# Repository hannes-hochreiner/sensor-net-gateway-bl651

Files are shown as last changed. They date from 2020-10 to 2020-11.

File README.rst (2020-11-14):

SensorNet Gateway BL651
=======================

A gateway for the SensorNet project, based on the BL651 module.

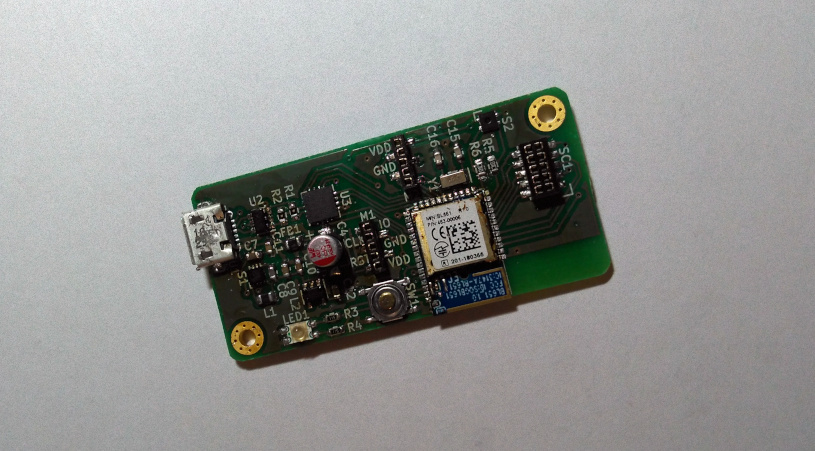
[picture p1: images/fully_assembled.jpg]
fully assembled board


Functional Test
---------------

+------------------+--------+
| feature          | status |
+==================+========+
| Power Management | OK     |
+------------------+--------+
| SWD              | OK     |
+------------------+--------+
| USB              | OK     |
+------------------+--------+
| LED              | OK     |
+------------------+--------+
| Sensor           | OK     |
+------------------+--------+

Firmware
--------

Firmware for this board can be found in the repository `"hannes-hochreiner/sensor-net-nrf52810-firmware" <https://github.com/hannes-hochreiner/sensor-net-nrf52810-firmware>`_

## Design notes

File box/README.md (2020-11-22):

Box Parameters
==============

PCB size
--------

24 x 50 x 1.6 mm

Mounting holes are M2; centers are 3 x 3 mm from corner

Components
----------

  * top side head room: 5.5 mm
  * Stand-off for inserts: 6 x 6 x 4 mm (5 mm in z recommended); hole diameter 3.2 mm; insert hight 4 mm
  * USB connector: cut-out 8.6 (8.2) x 3.4 (3) mm; center is 7 mm from PCB edge and 1.25 mm above PCB (1.25 + 1.6 + 4 = 6.85 mm from bottom of box)
  * Sensor: center on board 154,92; top left of board 152,82 => -10,15 from center of board

Required inner measurements
---------------------------

  * Height: 6 (5.5) + 4 + 2 (1.6) = 12 mm
  * Width: 24 + 2 x 6 = 36 mm
  * Depth: 50.2 (50) mm

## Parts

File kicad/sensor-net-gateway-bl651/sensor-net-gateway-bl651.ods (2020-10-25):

Status | Reference | Value | Footprint | Description | Digi-Key Part Number | Manufacturer | Manufacturer Part Number | DigiKey_PartNumber | Manufacturer_PartNumber
n/a | H2 | MountingHole | MountingHole:MountingHole_2.2mm_M2_Pad_Via
n/a | H1 | MountingHole | MountingHole:MountingHole_2.2mm_M2_Pad_Via
n/a | L3 | logo | HH_Hochreiner:logo
have | BL1 | BL651 | HH_Laird:BL651 | RX TXRX MODULE BT TRC ANT SMD | 453-00005CT-ND | Laird Connectivity Inc. | 453-00005
have | C14 | 0.1µF,16V | Capacitor_SMD:C_0603_1608Metric
order | Y1 | 32.768 kHz | Crystal:Crystal_SMD_MicroCrystal_CC7V-T1A-2Pin_3.2x1.5mm | CRYSTAL 32.7680KHZ 9PF SMD | 2195-CM7V-T1A-32.768KHZ-9PF-10PPM-TA-QCCT-ND | Micro Crystal AG | CM7V-T1A-32.768KHZ-9PF-10PPM-TA-QC
order | C15 | 9pF | Capacitor_SMD:C_0603_1608Metric |  | 311-3866-1-ND | Yageo | CC0603CRNPO9BN9R0
order | C16 | 9pF | Capacitor_SMD:C_0603_1608Metric |  | 311-3866-1-ND | Yageo | CC0603CRNPO9BN9R0
order | SW1 | PTS526_SM15_SMTR2_LFS | HH_CnK:PTS526-SM15-SMTR2-LFS | TACT 5.2 X 5.2, 1.5 MM H, 160GF | CKN12220-1-ND | C&K | PTS526 SM15 SMTR2 LFS
have | C13 | 0.1µF,16V | Capacitor_SMD:C_0603_1608Metric
order | SC1 | Sensor-Connector | HH_Hochreiner:Sensor-Connector_M50-3150542R | CONN RCPT 10POS 0.05 GOLD SMD | 952-3493-1-ND | Harwin Inc. | M50-3150542R
order | M1 | M50-3130545 | HH_Harwin:M50-3130545 |  | 952-3585-ND | Harwin Inc. |  | 952-3585-ND | M50-3130545
order | M2 | M50-3130545 | HH_Harwin:M50-3130545 |  | 952-3585-ND | Harwin Inc. |  | 952-3585-ND | M50-3130545
order | LED1 | APBD3224LSURKCGKC | HH_Kingbright:APBD3224LSURKCGKC | LED GREEN/RED CLEAR 4SMD | 754-1962-1-ND | Kingbright | APBD3224LSURKCGKC
order | R3 | 510 | Resistor_SMD:R_0603_1608Metric |  | RR08P510DCT-ND | Susumu | RR0816P-511-D
order | R4 | 510 | Resistor_SMD:R_0603_1608Metric |  | RR08P510DCT-ND | Susumu | RR0816P-511-D
have | C7 | 4.7µF | Capacitor_SMD:C_0603_1608Metric |  | 1276-1907-1-ND | Samsung Electro-Mechanics |  | 1276-1907-1-ND | CL10A475MQ8NNNC
have | L1 | 1µH | Inductor_SMD:L_0805_2012Metric |  |  |  |  | 445-6391-1-ND
order | C9 | 4.7µF | Capacitor_SMD:C_0603_1608Metric |  | 1276-1907-1-ND |  |  | 1276-1907-1-ND
have | C8 | 560pF | Capacitor_SMD:C_0603_1608Metric |  |  |  |  | 1276-2315-1-ND
have | C10 | 0.47µF | Capacitor_SMD:C_0603_1608Metric |  |  |  |  | 1276-2082-1-ND
have | C12 | 10µF | Capacitor_SMD:C_0603_1608Metric |  |  |  |  | 1276-1119-1-ND
have | S1 | MIC23050-SYML-TR | HH_MicrochipTechnology:MIC23050-SYML-TR | IC REG BUCK 3.3V 600MA 8MLF | 576-3351-1-ND | Microchip Technology | MIC23050-SYML-TR
have | L2 | MIC94310-MYM5-TR | Package_TO_SOT_SMD:SOT-23-5 | IC REG LINEAR 2.8V 200MA SOT23-5 | MIC94310-MYM5-CT-ND | Microchip Technology | MIC94310-MYM5-TR
have | C1 | 0.1µF | Capacitor_SMD:C_0603_1608Metric
have | C2 | 47pF | Capacitor_SMD:C_0603_1608Metric
have | C3 | 47pF | Capacitor_SMD:C_0603_1608Metric
have | R2 | 27R | Resistor_SMD:R_0603_1608Metric
have | R1 | 27R | Resistor_SMD:R_0603_1608Metric
have | C11 | 10nF | Capacitor_SMD:C_0603_1608Metric
have | C6 | 0.1µF | Capacitor_SMD:C_0603_1608Metric
have | C4 | 4.7µF | HH_WurthElektronik:865080640004 |  |  | Wurth Electronics Inc. |  | 732-8449-1-ND | 865080640004
have | C5 | 0.1µF | Capacitor_SMD:C_0603_1608Metric
have | C21 | 0.1µF | Capacitor_SMD:C_0603_1608Metric
have | U3 | FT230XQ | Package_DFN_QFN:QFN-16-1EP_4x4mm_P0.65mm_EP2.1x2.1mm | IC USB SERIAL BASIC UART 16QFN | 768-1130-1-ND | FTDI, Future Technology Devices International Ltd | FT230XQ-R
have | U1 | USB_micro_ab | HH_Molex:MOLEX_USB_MICRO_0475890001 | CONN RCPT MICRO USB AB 5P SMD RA | WM17143CT-ND | Molex | 0475890001
have | U2 | USBLC6-2SC6 | HH_STMicroelectronics:USBLC6-2SC6_SOT-23-6 | TVS DIODE 5.25V 17V SOT23-6 | 497-5235-1-ND | STMicroelectronics | USBLC6-2SC6
have | FB1 | Ferrite_Bead | Capacitor_SMD:C_0805_2012Metric | FERRITE BEAD 600 OHM 0805 1LN | 240-2390-1-ND | Laird-Signal Integrity Products | MI0805K601R-10
have | S2 | SHTC3 | HH_Sensirion:SHTC3 |  | 1649-1105-1-ND | Sensirion AG | SHTC3
have | R6 | 10k | Resistor_SMD:R_0603_1608Metric
have | R5 | 10k | Resistor_SMD:R_0603_1608Metric
have | C17 | 0.1µF | Capacitor_SMD:C_0603_1608Metric

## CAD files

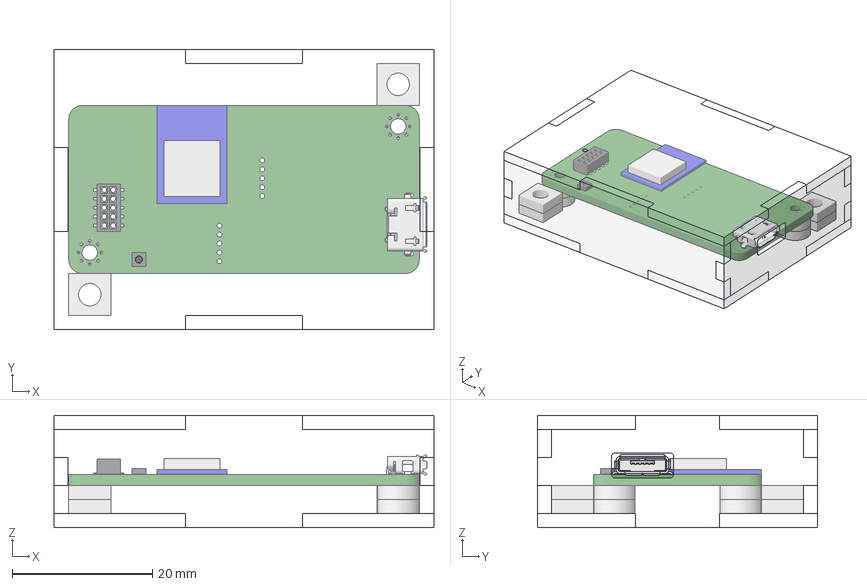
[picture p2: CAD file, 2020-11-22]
box/model.FCStd
54.2 x 40.0 x 16.0 mm
front
left
right
bottom
case_mounting_1_1
case_mounting_1_2
case_mounting_2_2
case_mounting_2_1
pcb_mount_1_1
pcb_mount_1_2
pcb_mount_2_1
pcb_mount_2_2
top
back

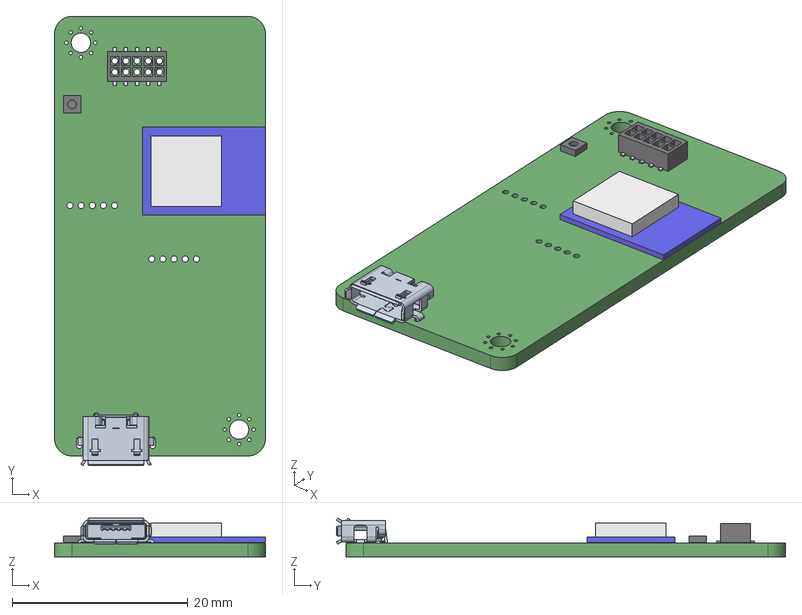
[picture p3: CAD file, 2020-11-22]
kicad/sensor-net-gateway-bl651/sensor-net-gateway-bl651.step
24.0 x 51.1 x 4.41 mm

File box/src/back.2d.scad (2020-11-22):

use <../lib/side.scad>

module back() {
  difference() {
    side_front_back(36,12,2);
    translate([-5,-12/2+6.85,0]) {
      offset(r=.3,$nf=50)
      polygon(points=[[-4.1,-1.5],[4.1,-1.5],[4.1,1.5],[-4.1,1.5],],convexity=10);
    }
  }
}

back();

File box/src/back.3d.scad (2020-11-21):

use <back.2d.scad>;

rotate([90,0,90]) {
  linear_extrude(height = 2, center = true, convexity = 10, twist = 0) {
    back();
  }
}

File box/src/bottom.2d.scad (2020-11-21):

use <../lib/side.scad>;

module bottom() {
  difference() {
    side_top_bottom(50.2,36,2);
    translate([-22,-15,0]) {
      circle(d=2.2, $fn=50);
    }
    translate([22,15,0]) {
      circle(d=2.2, $fn=50);
    }
  }
}

bottom();

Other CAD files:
box/src/bottom.3d.scad
box/src/box_mount.2d.scad
box/src/box_mount.3d.scad
box/src/combined.scad
box/src/front.2d.scad
box/src/front.3d.scad
box/src/left.2d.scad
box/src/left.3d.scad
box/src/mounting.2d.scad
box/src/mounting.3d.scad
box/src/pcb_mount.2d.scad
box/src/pcb_mount.3d.scad
box/src/top.2d.scad
box/src/top.3d.scad

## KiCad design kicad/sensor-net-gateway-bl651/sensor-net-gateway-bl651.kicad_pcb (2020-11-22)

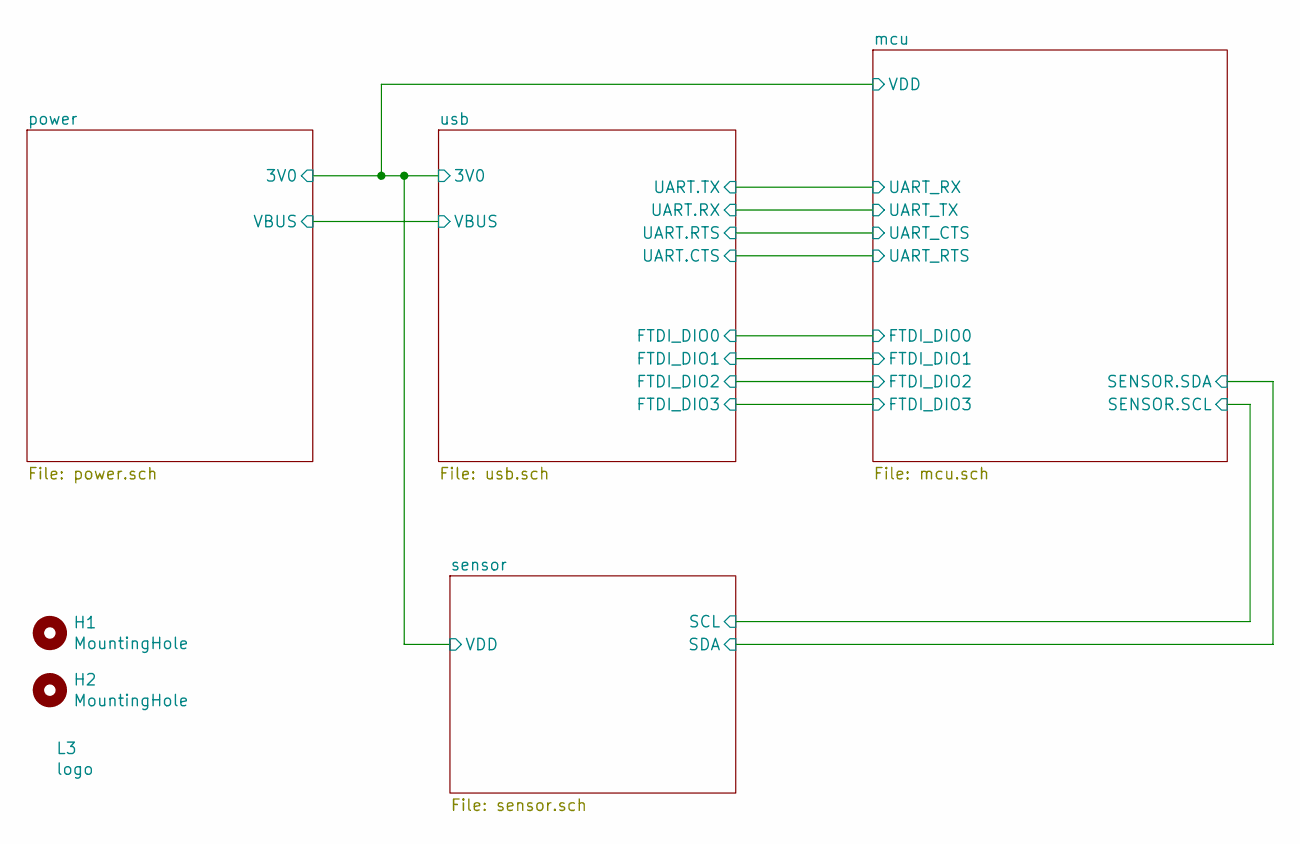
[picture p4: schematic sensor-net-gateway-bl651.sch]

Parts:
H1, H2: MountingHole; MountingHole_2.2mm_M2_Pad_Via
L3: logo

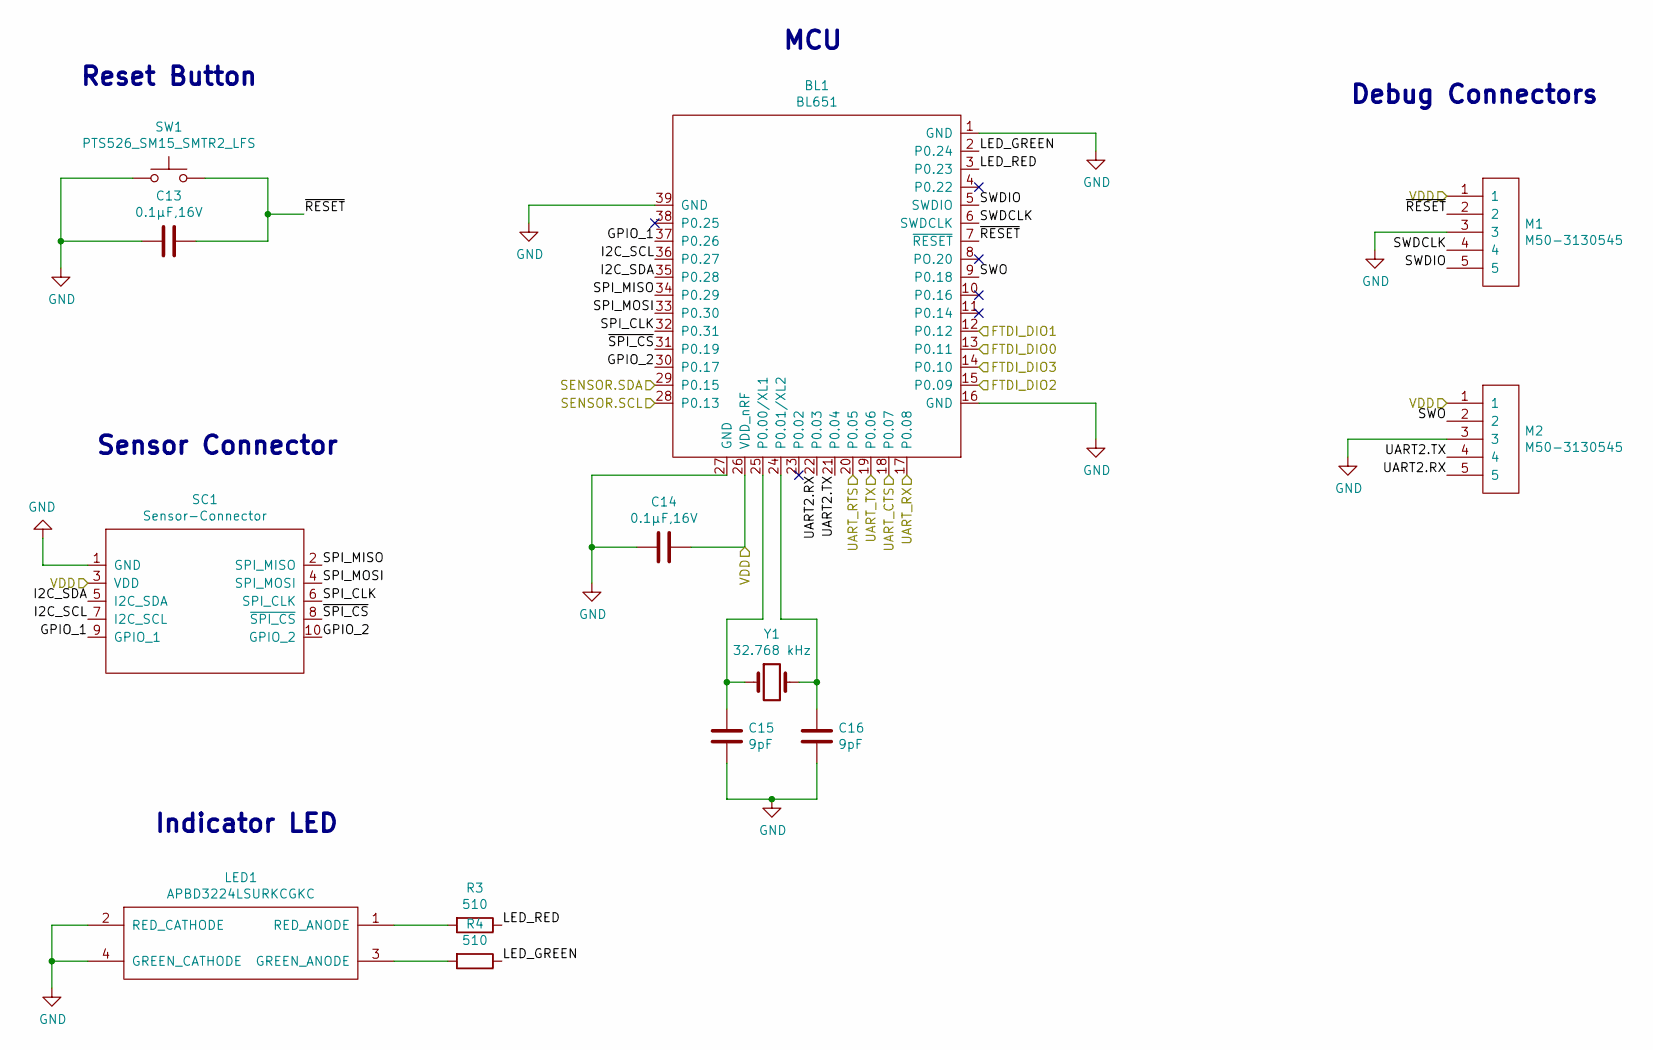
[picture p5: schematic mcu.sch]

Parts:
BL1: BL651; Manufacturer Part Number 453-00005; Digi-Key Part Number 453-00005CT-ND
C13, C14: 0.1µF,16V; C_0603_1608Metric
C15, C16: 9pF; C_0603_1608Metric; Manufacturer Part Number CC0603CRNPO9BN9R0; Digi-Key Part Number 311-3866-1-ND
LED1: APBD3224LSURKCGKC; Manufacturer Part Number APBD3224LSURKCGKC; Digi-Key Part Number 754-1962-1-ND
M1, M2: M50-3130545; Manufacturer_PartNumber M50-3130545; DigiKey_PartNumber 952-3585-ND
R3, R4: 510; R_0603_1608Metric; Manufacturer Part Number RR0816P-511-D; Digi-Key Part Number RR08P510DCT-ND
SC1: Sensor-Connector; Sensor-Connector_M50-3150542R; Manufacturer Part Number M50-3150542R; Digi-Key Part Number 952-3493-1-ND
SW1: PTS526_SM15_SMTR2_LFS; PTS526-SM15-SMTR2-LFS; Manufacturer Part Number PTS526 SM15 SMTR2 LFS; Digi-Key Part Number CKN12220-1-ND
Y1: 32.768 kHz; Crystal_SMD_MicroCrystal_CC7V-T1A-2Pin_3.2x1.5mm; Manufacturer Part Number CM7V-T1A-32.768KHZ-9PF-10PPM-TA-QC; Digi-Key Part Number 2195-CM7V-T1A-32.768KHZ-9PF-10PPM-TA-QC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

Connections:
/mcu/FTDI_DIO0: BL1.13 (P0.11); also elsewhere on the board
/mcu/FTDI_DIO1: BL1.12 (P0.12); also elsewhere on the board
/mcu/FTDI_DIO2: BL1.15 (P0.09); also elsewhere on the board
/mcu/FTDI_DIO3: BL1.14 (P0.10); also elsewhere on the board
/mcu/GPIO_1: BL1.37 (P0.26), SC1.9 (GPIO_1)
/mcu/GPIO_2: BL1.30 (P0.17), SC1.10 (GPIO_2)
/mcu/I2C_SCL: BL1.36 (P0.27), SC1.7 (I2C_SCL)
/mcu/I2C_SDA: BL1.35 (P0.28), SC1.5 (I2C_SDA)
/mcu/LED_GREEN: BL1.2 (P0.24), R4.1
/mcu/LED_RED: BL1.3 (P0.23), R3.1
/mcu/SPI_CLK: BL1.32 (P0.31), SC1.6 (SPI_CLK)
/mcu/SPI_MISO: BL1.34 (P0.29), SC1.2 (SPI_MISO)
/mcu/SPI_MOSI: BL1.33 (P0.30), SC1.4 (SPI_MOSI)
/mcu/SWDCLK: BL1.6 (SWDCLK), M1.4
/mcu/SWDIO: BL1.5 (SWDIO), M1.5
/mcu/SWO: BL1.9 (P0.18), M2.2
/mcu/UART2.RX: BL1.22 (P0.03), M2.5
/mcu/UART2.TX: BL1.21 (P0.04), M2.4
/mcu/~RESET: BL1.7 (~RESET), C13.1, M1.2, SW1.2
/mcu/~SPI_CS: BL1.31 (P0.19), SC1.8 (~SPI_CS)
/power/3V0: BL1.26 (VDD_nRF), C14.1, M1.1, M2.1, SC1.3 (VDD); also elsewhere on the board
/sensor/SCL: BL1.28 (P0.13); also elsewhere on the board
/sensor/SDA: BL1.29 (P0.15); also elsewhere on the board
/usb/UART.CTS: BL1.20 (P0.05); also elsewhere on the board
/usb/UART.RTS: BL1.18 (P0.07); also elsewhere on the board
/usb/UART.RX: BL1.19 (P0.06); also elsewhere on the board
/usb/UART.TX: BL1.17 (P0.08); also elsewhere on the board
GND: BL1.1 (GND), BL1.16 (GND), BL1.27 (GND), BL1.39 (GND), C13.2, C14.2, C15.2, C16.2, LED1.2 (RED_CATHODE), LED1.4 (GREEN_CATHODE), M1.3, M2.3, SC1.1 (GND), SW1.1; also elsewhere on the board
unnamed: BL1.24 (P0.01/XL2), C16.1, Y1.2
unnamed: BL1.25 (P0.00/XL1), C15.1, Y1.1
unnamed: LED1.1 (RED_ANODE), R3.2
unnamed: LED1.3 (GREEN_ANODE), R4.2

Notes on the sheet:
Indicator LED
Sensor Connector
Reset Button
MCU
Debug Connectors

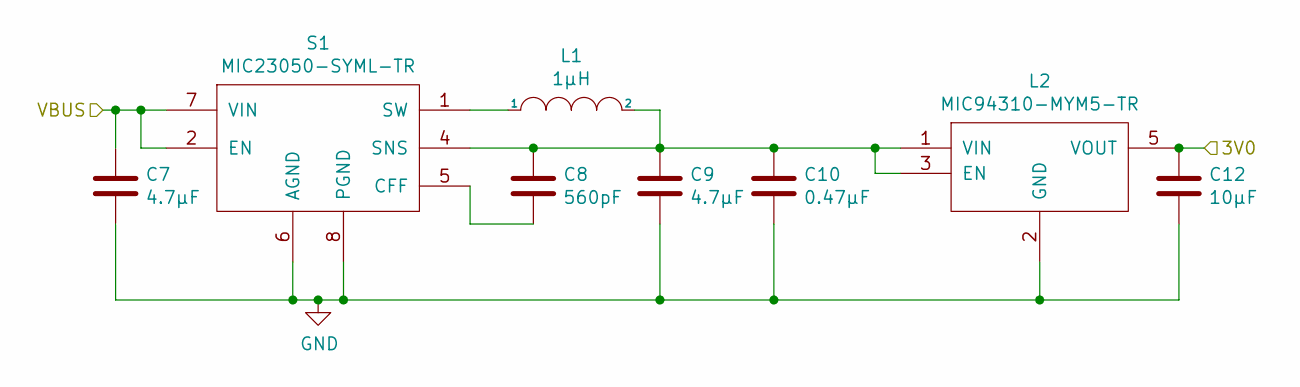
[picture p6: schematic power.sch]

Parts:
C7: 4.7µF; C_0603_1608Metric; Manufacturer_PartNumber CL10A475MQ8NNNC; DigiKey_PartNumber 1276-1907-1-ND
C8: 560pF; C_0603_1608Metric; DigiKey_PartNumber 1276-2315-1-ND
C9: 4.7µF; C_0603_1608Metric; DigiKey_PartNumber 1276-1907-1-ND
C10: 0.47µF; C_0603_1608Metric; DigiKey_PartNumber 1276-2082-1-ND
C12: 10µF; C_0603_1608Metric; DigiKey_PartNumber 1276-1119-1-ND
L1: 1µH; L_0805_2012Metric; DigiKey_PartNumber 445-6391-1-ND
L2: MIC94310-MYM5-TR; SOT-23-5; Manufacturer Part Number MIC94310-MYM5-TR; Digi-Key Part Number MIC94310-MYM5-CT-ND
S1: MIC23050-SYML-TR; Manufacturer Part Number MIC23050-SYML-TR; Digi-Key Part Number 576-3351-1-ND

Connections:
/power/3V0: C12.1, L2.5 (VOUT); also elsewhere on the board
/power/VBUS: C7.1, S1.2 (EN), S1.7 (VIN); also elsewhere on the board
GND: C7.2, C9.2, C10.2, C12.2, L2.2 (GND), S1.6 (AGND), S1.8 (PGND); also elsewhere on the board
unnamed: C8.2, S1.5 (CFF)
unnamed: C8.1, C9.1, C10.1, L1.2, L2.1 (VIN), L2.3 (EN), S1.4 (SNS)
unnamed: L1.1, S1.1 (SW)

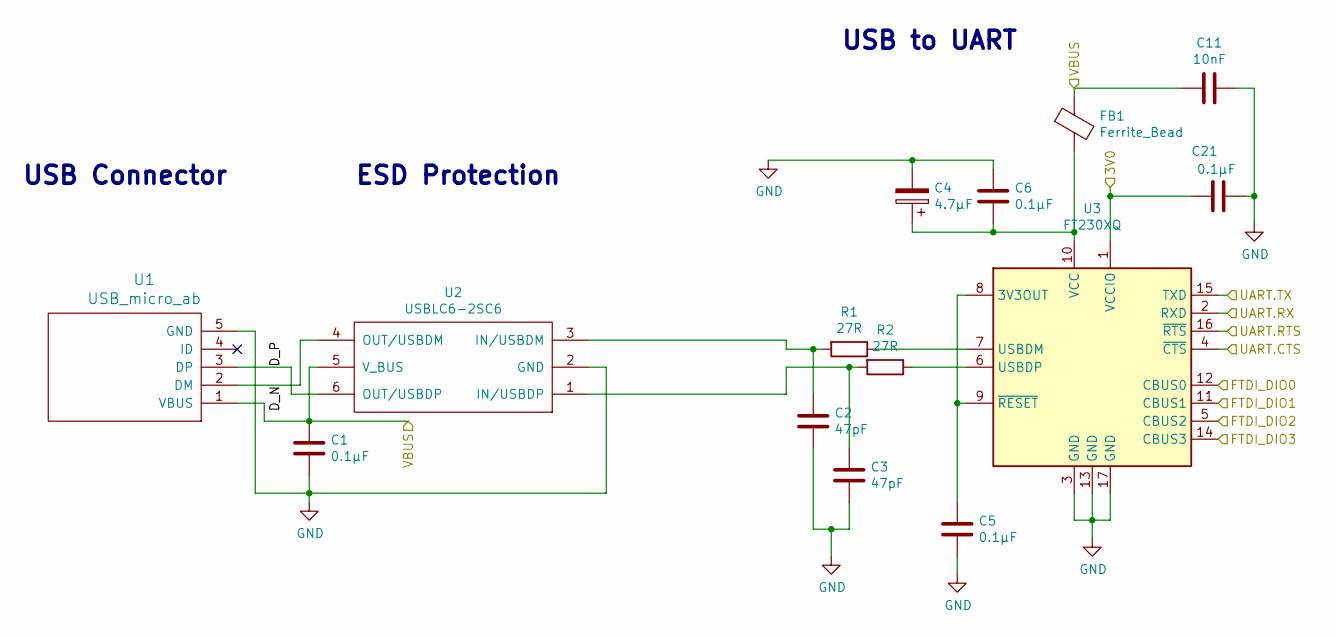
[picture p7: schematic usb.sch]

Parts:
C1, C5, C6, C21: 0.1µF; C_0603_1608Metric
C2, C3: 47pF; C_0603_1608Metric
C4: 4.7µF; 865080640004; Manufacturer_PartNumber 865080640004; DigiKey_PartNumber 732-8449-1-ND
C11: 10nF; C_0603_1608Metric
FB1: Ferrite_Bead; C_0805_2012Metric; Manufacturer Part Number MI0805K601R-10; Digi-Key Part Number 240-2390-1-ND
R1, R2: 27R; R_0603_1608Metric
U1: USB_micro_ab; MOLEX_USB_MICRO_0475890001; Manufacturer Part Number 0475890001; Digi-Key Part Number WM17143CT-ND
U2: USBLC6-2SC6; USBLC6-2SC6_SOT-23-6; Manufacturer Part Number USBLC6-2SC6; Digi-Key Part Number 497-5235-1-ND
U3: FT230XQ; QFN-16-1EP_4x4mm_P0.65mm_EP2.1x2.1mm; Manufacturer Part Number FT230XQ-R; Digi-Key Part Number 768-1130-1-ND

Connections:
/mcu/FTDI_DIO0: U3.12 (CBUS0); also elsewhere on the board
/mcu/FTDI_DIO1: U3.11 (CBUS1); also elsewhere on the board
/mcu/FTDI_DIO2: U3.5 (CBUS2); also elsewhere on the board
/mcu/FTDI_DIO3: U3.14 (CBUS3); also elsewhere on the board
/power/3V0: C21.1, U3.1 (VCCIO); also elsewhere on the board
/power/VBUS: C1.1, C11.1, FB1.1, U1.1 (VBUS), U2.5 (V_BUS); also elsewhere on the board
/usb/D_N: U1.2 (DM), U2.4 (OUT/USBDM)
/usb/D_P: U1.3 (DP), U2.6 (OUT/USBDP)
/usb/UART.CTS: U3.4 (~CTS); also elsewhere on the board
/usb/UART.RTS: U3.16 (~RTS); also elsewhere on the board
/usb/UART.RX: U3.2 (RXD); also elsewhere on the board
/usb/UART.TX: U3.15 (TXD); also elsewhere on the board
GND: C1.2, C2.2, C3.2, C4.2, C5.2, C6.1, C11.2, C21.2, U1.5 (GND), U2.2 (GND), U3.3 (GND), U3.13 (GND), U3.17 (GND); also elsewhere on the board
unnamed: C2.1, R1.2, U2.3 (IN/USBDM)
unnamed: C3.1, R2.2, U2.1 (IN/USBDP)
unnamed: C4.1, C6.2, FB1.2, U3.10 (VCC)
unnamed: C5.1, U3.8 (3V3OUT), U3.9 (~RESET)
unnamed: R1.1, U3.7 (USBDM)
unnamed: R2.1, U3.6 (USBDP)

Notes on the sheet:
USB Connector
ESD Protection
USB to UART

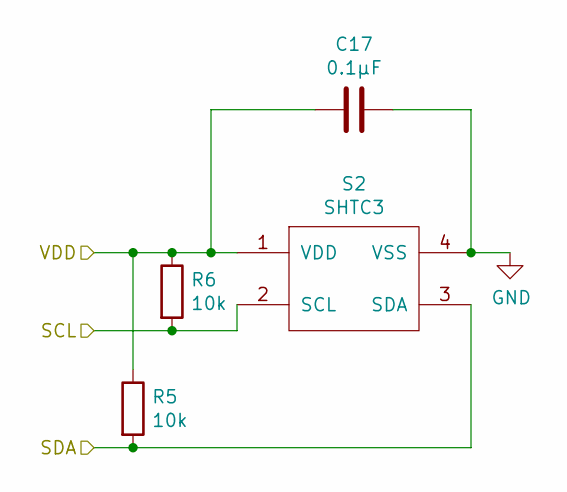
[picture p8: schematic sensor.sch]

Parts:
C17: 0.1µF; C_0603_1608Metric
R5, R6: 10k; R_0603_1608Metric
S2: SHTC3; Manufacturer Part Number SHTC3; Digi-Key Part Number 1649-1105-1-ND

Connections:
/power/3V0: C17.2, R5.1, R6.1, S2.1 (VDD); also elsewhere on the board
/sensor/SCL: R6.2, S2.2 (SCL); also elsewhere on the board
/sensor/SDA: R5.2, S2.3 (SDA); also elsewhere on the board
GND: C17.1, S2.4 (VSS); also elsewhere on the board

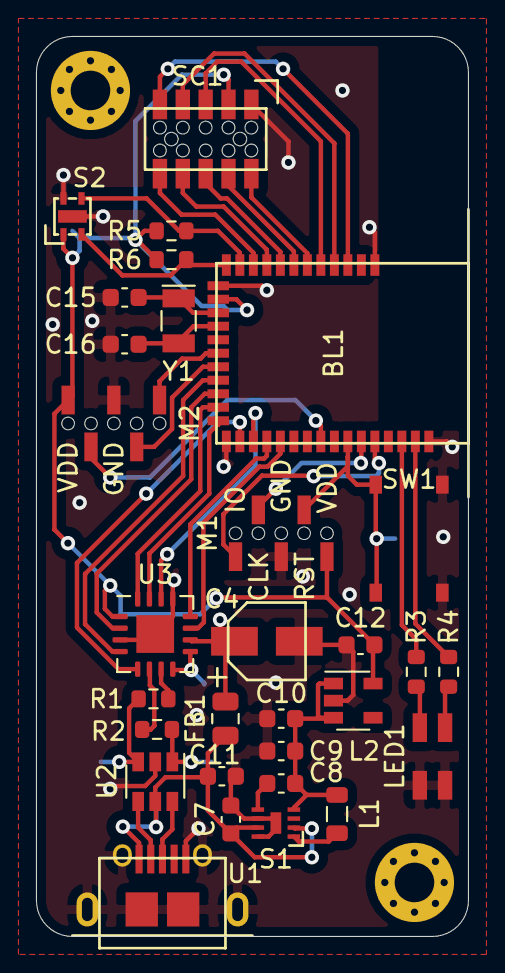
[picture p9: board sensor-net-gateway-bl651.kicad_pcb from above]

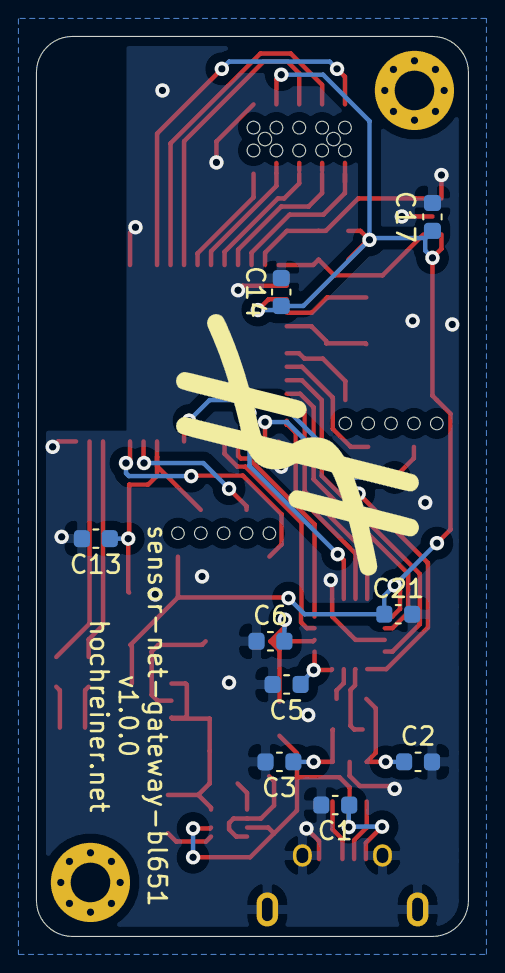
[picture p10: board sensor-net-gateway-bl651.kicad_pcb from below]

Board: 2 copper layers, 24.0 x 50.0 mm, 42 parts (10 on the bottom side), 44 nets.

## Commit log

2020-10-18 started schematic
    [mcu.sch, power.sch, sensor-net-gateway-bl651.kicad_pcb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]
2020-10-19 added power and usb2uart
    [mcu.sch, power.sch, sensor-net-gateway-bl651.sch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]
2020-10-20 started layout
    [mcu.sch, power.sch, sensor-net-gateway-bl651.kicad_pcb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]
2020-10-25 routing snapshot
    [mcu.sch, power.sch, sensor-net-gateway-bl651.kicad_pcb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]
2020-10-25 added pin descriptions
    [mcu.sch, power.sch, sensor-net-gateway-bl651.kicad_pcb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]
2020-10-25 added BOM
    [sensor-net-gateway-bl651.ods]
2020-11-12 refactored sensor code
2020-11-21 add case
    [back.2d.scad, back.3d.scad, bottom.2d.scad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]
2020-11-21 update model
    [model.FCStd]
2020-11-22 add hole for sensor
    [top.2d.scad]
2020-11-22 update pcb model
    [sensor-net-gateway-bl651.kicad_pcb, sensor-net-gateway-bl651.step]
2020-11-22 update pcb mount
    [back.2d.scad, box_mount.2d.scad, box_mount.3d.scad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]
